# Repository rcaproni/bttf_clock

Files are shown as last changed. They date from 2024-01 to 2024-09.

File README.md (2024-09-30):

# Back to the Future clock

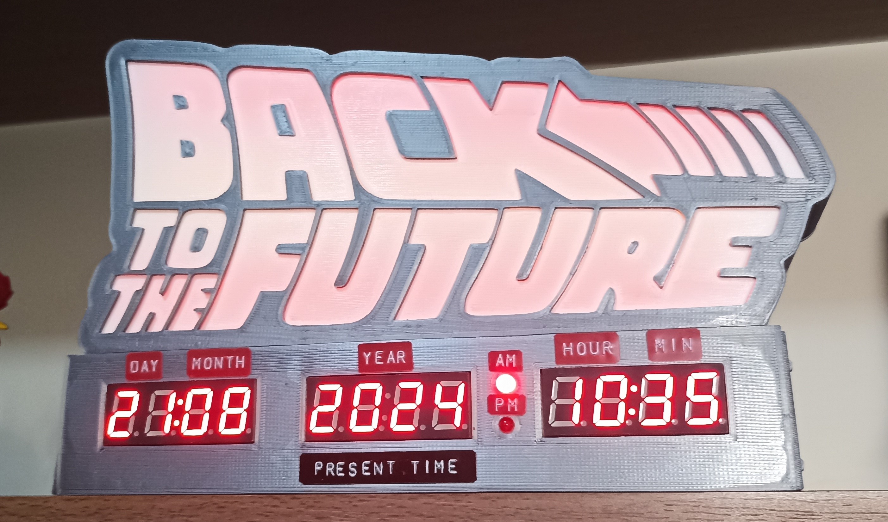
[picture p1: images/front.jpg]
  

Based on the design by jerome95 from [Instructables](https://www.instructables.com/Back-to-the-Future-Lamp-Clock/?utm_source=newsletter&utm_medium=email), I took on my first 3D printing project: a clock inspired by the *Back to the Future* DeLorean Time Circuits. This clock is controlled by an ESP32 Mini and syncs the time over the internet using an NTP client.

I'm a big fan of the BTTF trilogy. The first project I decided to tackle when I acquired a 3D printer was the clock designed by jerome95. The original project uses the aesthetics of BTTF's DeLorean Time Circuits. The clock is controlled by an ESP32 Mini and synchronizes the time over the internet using an NTP client.

For my design, I made some changes to the original:

- **Case modification for small printers**: The original case was too large for my Ender3, so I divided it into two parts using SketchUp. I added internal pins to ensure the two halves could be glued securely. The modified STL files are available in the 3D folder.
  
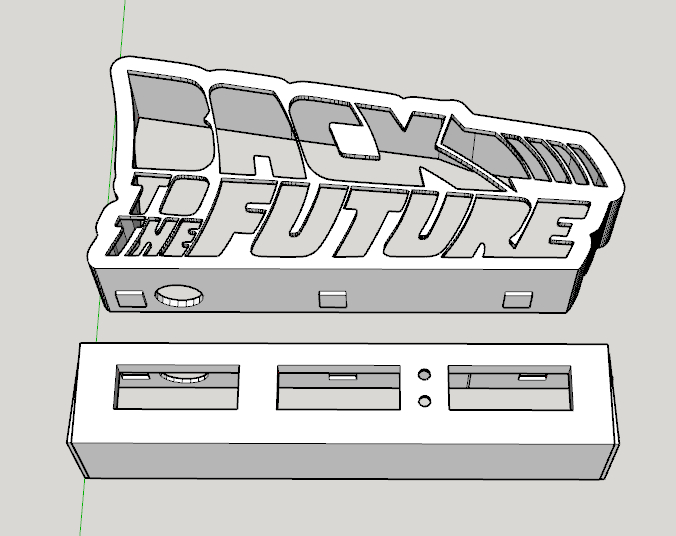
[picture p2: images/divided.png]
  
  
- **Display order**: I adapted the display format to the Brazilian time format: DD:MM YYYY AM/PM HH:MM.

- **ESP32 Board**: Since I couldn’t find the ESP32 Mini locally, I used a NodeMcu 3.0 instead. Though I initially planned to use the same firmware, I made several changes to accommodate the new hardware.
- **RTC Integration**: I added an RTC module to keep the time accurate when the device is offline. This module is powered by a battery and can be configured through the web server. I made minor tweaks to the SlowSoftI2CMaster library to improve I2C communication by adding slight delays to the `i2c_init` and `i2c_start` functions.

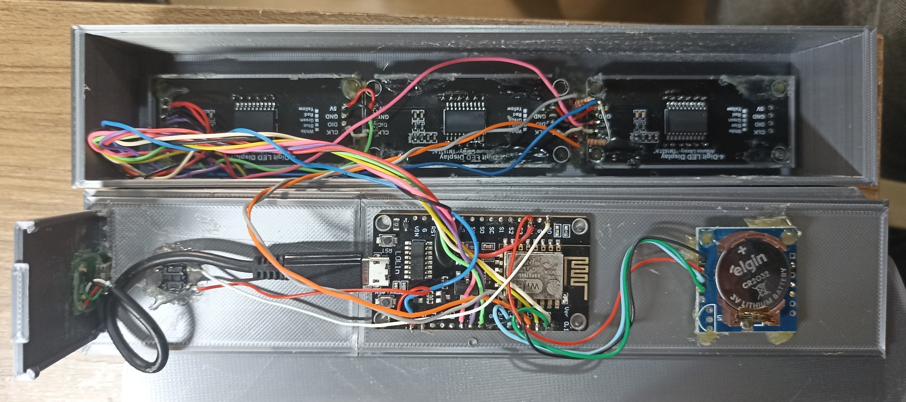
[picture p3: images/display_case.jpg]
  

- **Sacrificial pixel**: I added a sacrificial pixel to the LED string following [this guide](https://hackaday.com/2017/01/20/cheating-at-5v-ws2812-control-to-use-a-3-3v-data-line) to ensure proper 3.3V data line control.

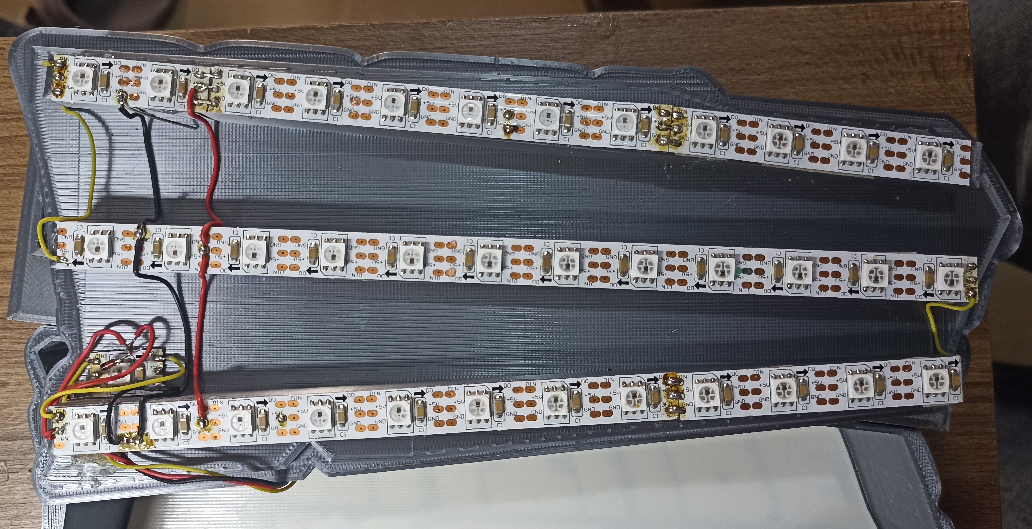
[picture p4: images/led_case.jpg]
  
  
- **Web Server**: Instead of using NTP sync, I implemented a web server based on [Kris Kasprzak's code](https://github.com/KrisKasprzak/ESP32_WebPage). The server allows users to configure the time and date, control LED and display brightness, and retrieve time data from the RTC. Clicking "Get Local Time" populates fields with the current time from the accessing device (web browser), while "Prog RTC Time" programs the RTC module. 
The LED brightness and display brightness sliders will adjust the brightness of the LED strip and the time displays.
Scene Setup is a work in progress, and my goal is to synchronize LED colors and brightness with the current time.

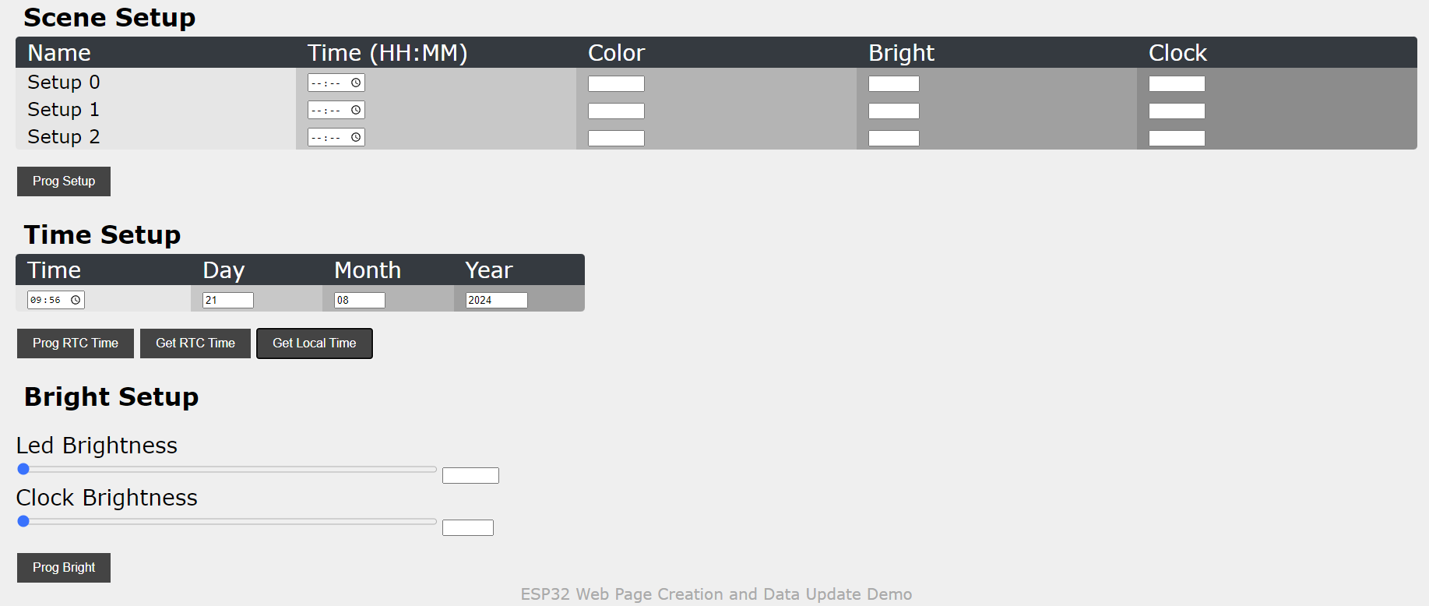
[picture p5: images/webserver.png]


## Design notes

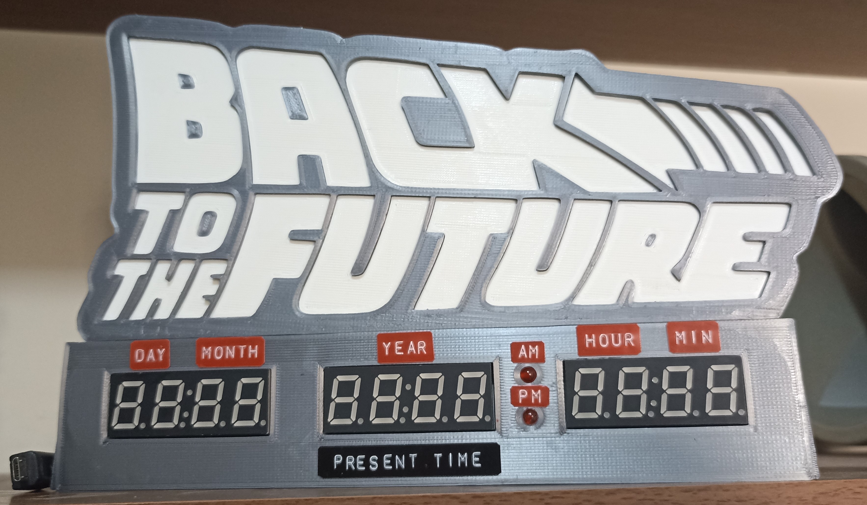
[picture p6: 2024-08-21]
images/front_off.jpg

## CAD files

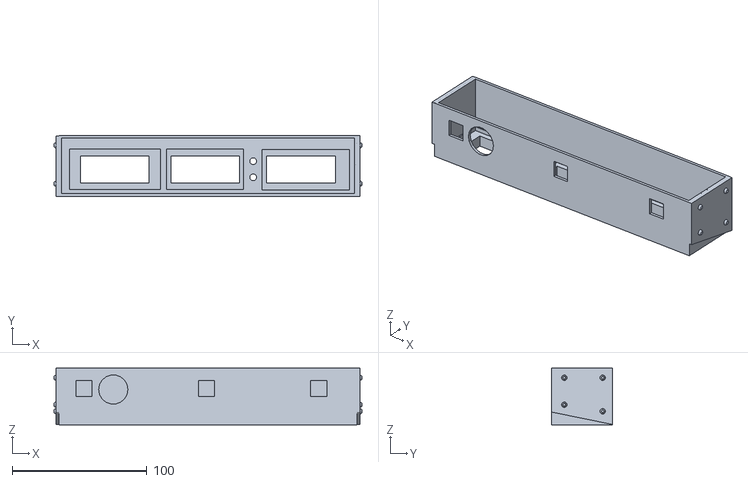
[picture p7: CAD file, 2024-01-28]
3d/clock_only.stl
228.2 x 45.2 x 42.1

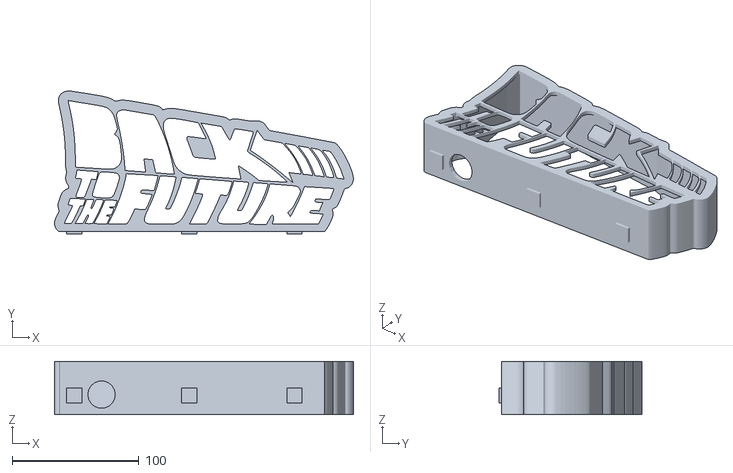
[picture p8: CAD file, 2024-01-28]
3d/box_only.stl
236.0 x 113.2 x 42.0

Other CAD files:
3d/box_only.skp
3d/clock_only.skp

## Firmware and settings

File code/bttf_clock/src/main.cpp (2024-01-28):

// BBTF clock ESP32 code -  Based in the original work of jerome95: https://www.instructables.com/Back-to-the-Future-Lamp-Clock/
// Webserver based on code from here: https://github.com/KrisKasprzak/ESP32_WebPage
// Get time from RTC instead of NTP server. Uses webserver for configuration and time adjustment.
// Author: Rodolfo Caproni
// License: MIT
// Version: 1.0
// Date: 2023-01-28


#include <Arduino.h>

#include "display.h"
#include "rtc.h"
#include "strip.h"
#include "webserver.h"

// switch analog input
#define SWITCH A0

WebServer webserver;
RTC rtc;
disp_t dispTime;

/**
 * Check the status of the switch.
 *
 * @return HIGH if the switch is pressed, LOW if the switch is open
 */
bool check_switch(){
  if(analogRead(SWITCH) > 1000){
    Serial.println("switch pressed\n");
    return HIGH;
  }
  else{
    Serial.println("switch open\n");
    return LOW;
  }
}


/**
 * Function to set up the pins, serial, and webserver.
  */
void setup() {
  // pins setup
  pinMode(LED_BUILTIN, OUTPUT);     // Initialize the LED_BUILTIN pin as an output
  pinMode(SWITCH, INPUT);

  // serial setup
  Serial.begin(9600);
  Serial.println("Serial ON");

  // init webserver
  webserver.init();
}


/**
 * This function runs a loop that checks a switch, reads the real-time clock date,
 * prints the time to the display, handles any incoming webserver commands, and
 * then introduces a delay before the loop restarts.
 */
void loop() {
  check_switch();
  dispTime = rtc.readRtcDate();
  delay(500);
  webserver.printTime(dispTime);
  delay(500);
  webserver.handleClient();
  delay(3000);
}

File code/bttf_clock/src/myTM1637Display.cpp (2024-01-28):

//  Author: avishorp@gmail.com
//
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
extern "C" {
  #include <stdlib.h>
  #include <string.h>
  #include <inttypes.h>
}

#include <myTM1637Display.h>
#include <Arduino.h>

#define TM1637_I2C_COMM1    0x40
#define TM1637_I2C_COMM2    0xC0
#define TM1637_I2C_COMM3    0x80

//
//      A
//     ---
//  F |   | B
//     -G-
//  E |   | C
//     ---
//      D
const uint8_t digitToSegment[] = {
 // XGFEDCBA
  0b00111111,    // 0
  0b00000110,    // 1
  0b01011011,    // 2
  0b01001111,    // 3
  0b01100110,    // 4
  0b01101101,    // 5
  0b01111101,    // 6
  0b00000111,    // 7
  0b01111111,    // 8
  0b01101111,    // 9
  0b01110111,    // A
  0b01111100,    // b
  0b00111001,    // C
  0b01011110,    // d
  0b01111001,    // E
  0b01110001     // F
  };

static const uint8_t minusSegments = 0b01000000;

myTM1637Display::myTM1637Display(uint8_t pinClk, uint8_t pinDIO, unsigned int bitDelay):
                i2c(pinDIO, pinClk, true)
{
	// Copy the pin numbers
	m_pinClk = pinClk;
	m_pinDIO = pinDIO;
	m_bitDelay = bitDelay;

	// Set the pin direction and default value.
	// Both pins are set as inputs, allowing the pull-up resistors to pull them up
    pinMode(m_pinClk, INPUT);
    pinMode(m_pinDIO,INPUT);
	digitalWrite(m_pinClk, LOW);
	digitalWrite(m_pinDIO, LOW);
}

void myTM1637Display::setBrightness(uint8_t brightness, bool on)
{
	m_brightness = (brightness & 0x7) | (on? 0x08 : 0x00);
}

void myTM1637Display::setSegments(const uint8_t segments[], uint8_t length, uint8_t pos)
{
   // Write COMM1
	start();
	writeByte(TM1637_I2C_COMM1);
	stop();

	// Write COMM2 + first digit address
	start();
	writeByte(TM1637_I2C_COMM2 + (pos & 0x03));

	// Write the data bytes
	for (uint8_t k=0; k < length; k++)
	  writeByte(segments[k]);

	stop();

	// Write COMM3 + brightness
	start();
	writeByte(TM1637_I2C_COMM3 + (m_brightness & 0x0f));
	stop();
}

void myTM1637Display::clear()
{
    uint8_t data[] = { 0, 0, 0, 0 };
	setSegments(data);
}

void myTM1637Display::showNumberDec(int num, bool leading_zero, uint8_t length, uint8_t pos)
{
  showNumberDecEx(num, 0, leading_zero, length, pos);
}

void myTM1637Display::showNumberDecEx(int num, uint8_t dots, bool leading_zero,
                                    uint8_t length, uint8_t pos)
{
  showNumberBaseEx(num < 0? -10 : 10, num < 0? -num : num, dots, leading_zero, length, pos);
}

void myTM1637Display::showNumberHexEx(uint16_t num, uint8_t dots, bool leading_zero,
                                    uint8_t length, uint8_t pos)
{
  showNumberBaseEx(16, num, dots, leading_zero, length, pos);
}

void myTM1637Display::showNumberBaseEx(int8_t base, uint16_t num, uint8_t dots, bool leading_zero,
                                    uint8_t length, uint8_t pos)
{
    bool negative = false;
	if (base < 0) {
	    base = -base;
		negative = true;
	}


    uint8_t digits[4];

	if (num == 0 && !leading_zero) {
		// Singular case - take care separately
		for(uint8_t i = 0; i < (length-1); i++)
			digits[i] = 0;
		digits[length-1] = encodeDigit(0);
	}
	else {
		//uint8_t i = length-1;
		//if (negative) {
		//	// Negative number, show the minus sign
		//    digits[i] = minusSegments;
		//	i--;
		//}
		
		for(int i = length-1; i >= 0; --i)
		{
		    uint8_t digit = num % base;
			
			if (digit == 0 && num == 0 && leading_zero == false)
			    // Leading zero is blank
				digits[i] = 0;
			else
			    digits[i] = encodeDigit(digit);
				
			if (digit == 0 && num == 0 && negative) {
			    digits[i] = minusSegments;
				negative = false;
			}

			num /= base;
		}
    }
	
	if(dots != 0)
	{
		showDots(dots, digits);
	}
    
    //setSegments(digits, length, pos);
    setSegments_i2c(digits, length, pos);
}

void myTM1637Display::bitDelay()
{
	delayMicroseconds(m_bitDelay);
}

void myTM1637Display::start()
{
  pinMode(m_pinDIO, OUTPUT);
  bitDelay();
}

void myTM1637Display::stop()
{
	pinMode(m_pinDIO, OUTPUT);
	bitDelay();
	pinMode(m_pinClk, INPUT);
	bitDelay();
	pinMode(m_pinDIO, INPUT);
	bitDelay();
}

bool myTM1637Display::writeByte(uint8_t b)
{
  uint8_t data = b;

  // 8 Data Bits
  for(uint8_t i = 0; i < 8; i++) {
    // CLK low
    pinMode(m_pinClk, OUTPUT);
    bitDelay();

	// Set data bit
    if (data & 0x01)
      pinMode(m_pinDIO, INPUT);
    else
      pinMode(m_pinDIO, OUTPUT);

    bitDelay();

	// CLK high
    pinMode(m_pinClk, INPUT);
    bitDelay();
    data = data >> 1;
  }

  // Wait for acknowledge
  // CLK to zero
  pinMode(m_pinClk, OUTPUT);
  pinMode(m_pinDIO, INPUT);
  bitDelay();

  // CLK to high
  pinMode(m_pinClk, INPUT);
  bitDelay();
  uint8_t ack = digitalRead(m_pinDIO);
  if (ack == 0)
    pinMode(m_pinDIO, OUTPUT);


  bitDelay();
  pinMode(m_pinClk, OUTPUT);
  bitDelay();

  return ack;
}

void myTM1637Display::showDots(uint8_t dots, uint8_t* digits)
{
    for(int i = 0; i < 4; ++i)
    {
        digits[i] |= (dots & 0x80);
        dots <<= 1;
    }
}

uint8_t myTM1637Display::encodeDigit(uint8_t digit)
{
	return digitToSegment[digit & 0x0f];
}


// added by Rodolfo
// added to deal with bus share in SCL. 
// only worked for me using the I2C library
void myTM1637Display::setSegments_i2c(const uint8_t segments[], uint8_t length, uint8_t pos)
{
  Serial.println("myTM1637Display::setSegments_i2c");
  if (!i2c.i2c_init()) 
    Serial.println("I2C init error");
  else
    Serial.println("I2C OK");
  delayMicroseconds(500);

  // start
  i2c.i2c_start_disp();
  i2c.i2c_write_lsb(TM1637_I2C_COMM1);
  i2c.i2c_stop();
   // Write COMM1
	// start();
	// writeByte(TM1637_I2C_COMM1);
	// stop();

  i2c.i2c_start_disp();
  i2c.i2c_write_lsb(TM1637_I2C_COMM2 + (pos & 0x03));
  // Write COMM2 + first digit address
	// start();
	// writeByte(TM1637_I2C_COMM2 + (pos & 0x03));

	// Write the data bytes
	for (uint8_t k=0; k < length; k++)
    i2c.i2c_write_lsb(segments[k]);
	  //writeByte(segments[k]);

  i2c.i2c_stop();
	//stop();

  i2c.i2c_start_disp();
  i2c.i2c_write_lsb(TM1637_I2C_COMM3 + (m_brightness & 0x0f));
  i2c.i2c_stop();
	// Write COMM3 + brightness
	// start();
	// writeByte(TM1637_I2C_COMM3 + (m_brightness & 0x0f));
	// stop();
}
